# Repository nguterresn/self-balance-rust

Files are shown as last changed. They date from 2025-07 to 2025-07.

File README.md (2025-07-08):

# Self balacing robot in Rust 🦀

Simple to use and quick to print two wheel robot.

IMG_9873 – média

* [Code](https://github.com/nguterresn/self-balance-rust/tree/master/firmware)
* [Enclosure](https://github.com/nguterresn/self-balance-rust/tree/master/cad)

Requires:

* ESP32C3 (or equivalent)
* DRV8833 driver (or equivalent)
* MPU6050
* x2 n20 motor
* A battery (used a 7.4V one)
* x4 M3 screws (bottom)
* x4 M3 screws (lid)
* A small breadboard

The code is written in Rust and runs in a single loop. Due the single loop operation, the timings may not be the best, but the goal was achieved. I tried to wrap all the possible errors that could happen inside the main loop in such a way that it would not cause any strange _panic_ in case of error.

This is essentially an exploration of what can be achieved when Rust and the robotics field is mixed.

I'd like to point out a few things:

* Calibration.
* PID control.
* Slow/Fast Decay.
* PWM frequency.
* Wheels size.
* Gyro and accel direction.
* Filters.
* I2C packet loss/ FIFO packet loss.
* Starting angle.

All the above had some kind of impact in the development of the project. 

Since the motors do not include a encoder, the following project scope is only within the angle error mitigation, the so called "balance". Therefore, it does not garantee any cascade control.

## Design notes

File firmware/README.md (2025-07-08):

To run the PID live visualization:

```bash
python3 sim.py
```

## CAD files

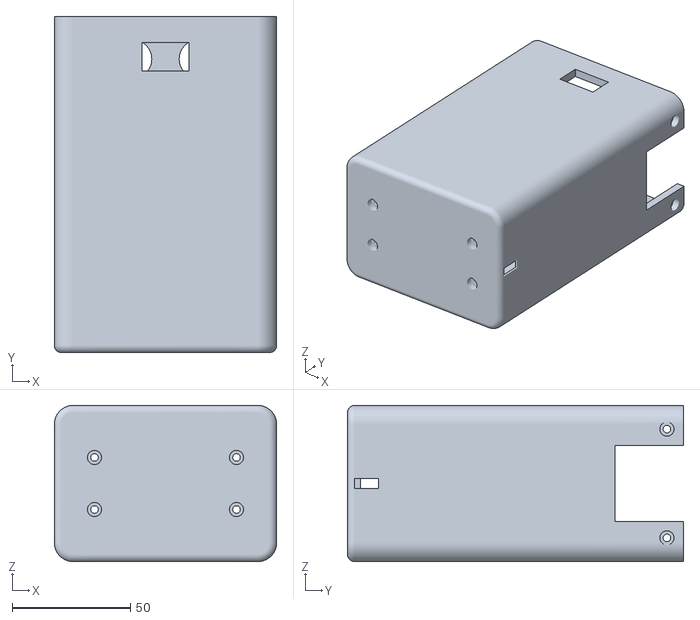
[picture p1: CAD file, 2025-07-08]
cad/Body.stl
94.0 x 142.0 x 66.0

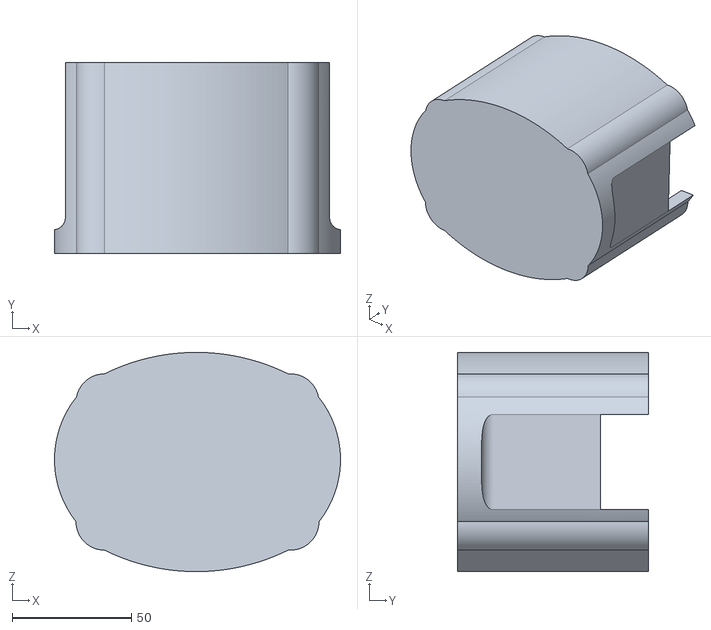
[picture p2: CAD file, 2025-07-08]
cad/Garage.stl
120.0 x 80.0 x 92.0

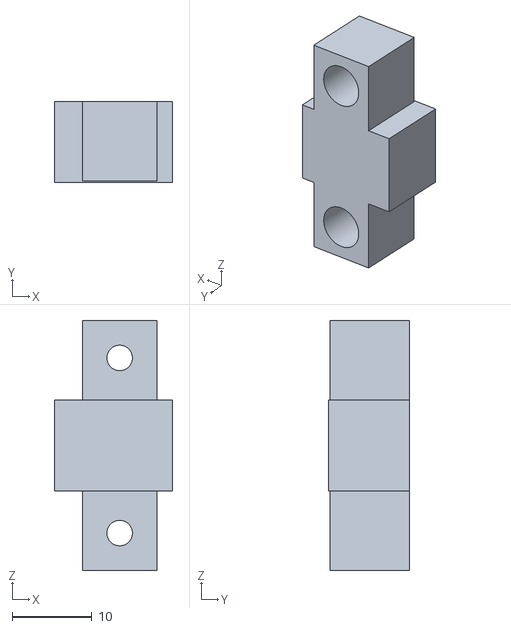
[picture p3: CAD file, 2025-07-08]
cad/Holder.stl
14.8 x 10.2 x 31.4

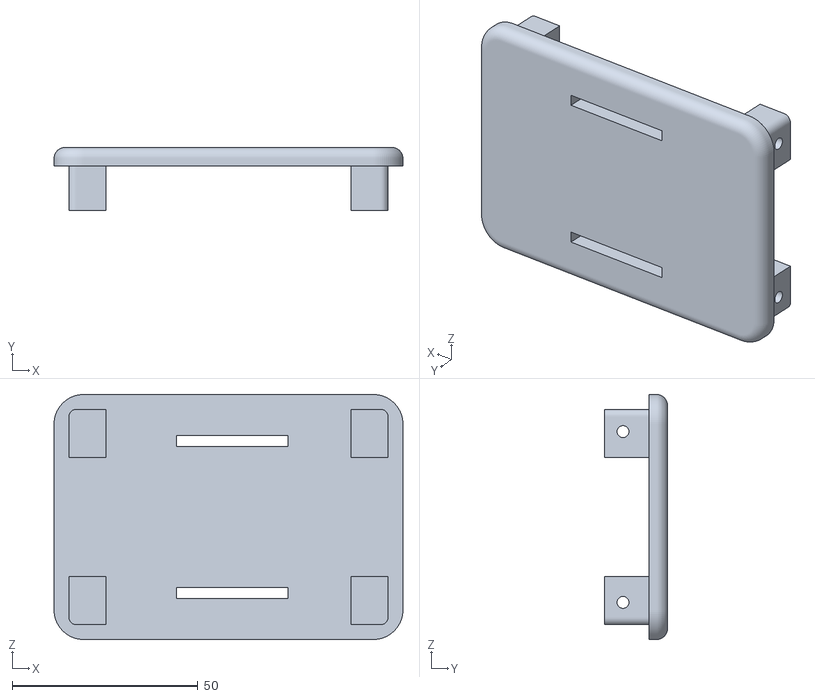
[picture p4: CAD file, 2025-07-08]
cad/Lid.stl
94.0 x 17.0 x 66.0

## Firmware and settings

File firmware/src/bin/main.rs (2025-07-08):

#![no_std]
#![no_main]

use esp_drv8833::drv8833::MotorLink;
use esp_drv8833::MotorTimer;
use esp_hal::clock::CpuClock;
use esp_hal::delay::Delay;
use esp_hal::i2c::master::{Config, I2c};
use esp_hal::ledc::{channel, timer, LSGlobalClkSource, Ledc};
use esp_hal::time::{Instant, Rate};
use esp_hal::{main, Blocking};
use esp_println::println;
use firmware::{BalanceControl, BalanceRobot};
use mpu6050_dmp::accel::{Accel, AccelFullScale};
use mpu6050_dmp::address::Address;
// use mpu6050_dmp::calibration::{CalibrationParameters, ReferenceGravity};
use mpu6050_dmp::error::Error;
use mpu6050_dmp::gyro::{Gyro, GyroFullScale};
use mpu6050_dmp::quaternion::Quaternion;
use mpu6050_dmp::sensor::Mpu6050;
use mpu6050_dmp::yaw_pitch_roll::YawPitchRoll;

#[panic_handler]
fn panic(info: &core::panic::PanicInfo) -> ! {
    println!("Panic! Msg: {}:{:?}", info.message(), info.location());
    loop {}
}

// First pair of values: (Accel { x: -52, y: 36, z: 16384 }, Gyro { x: 7, y: 7, z: 8 })

#[main]
fn main() -> ! {
    // generator version: 0.3.1

    let config = esp_hal::Config::default().with_cpu_clock(CpuClock::max());
    let peripherals = esp_hal::init(config);

    let mut ledc = Ledc::new(peripherals.LEDC);
    ledc.set_global_slow_clock(LSGlobalClkSource::APBClk);

    let motor_config = MotorTimer::new(
        &ledc,
        timer::Number::Timer0,
        timer::config::Duty::Duty7Bit,
        Rate::from_hz(500),
    )
    .unwrap();

    let mut robot = BalanceRobot::new(
        &ledc,
        &motor_config.timer,
        MotorLink::new(channel::Number::Channel1, peripherals.GPIO0),
        MotorLink::new(channel::Number::Channel0, peripherals.GPIO1),
        MotorLink::new(channel::Number::Channel3, peripherals.GPIO10),
        MotorLink::new(channel::Number::Channel2, peripherals.GPIO9),
    )
    .unwrap();
    robot.brake().unwrap();

    let mut delay = Delay::new();
    delay.delay_millis(1000);

    // Setup correctly the accelerometer

    let i2c = I2c::new(peripherals.I2C0, Config::default())
        .unwrap()
        .with_sda(peripherals.GPIO4)
        .with_scl(peripherals.GPIO3);

    let mut sensor: Mpu6050<I2c<'_, esp_hal::Blocking>> =
        Mpu6050::new(i2c, Address::default()).unwrap();

    let offsets = (Accel::new(-2656, -1231, 797), Gyro::new(181, -9, 26));

    sensor.initialize_dmp(&mut delay).unwrap();
    sensor.set_accel_full_scale(AccelFullScale::G2).unwrap();
    sensor.set_gyro_full_scale(GyroFullScale::Deg250).unwrap();
    sensor.set_accel_calibration(&offsets.0).unwrap();
    sensor.set_gyro_calibration(&offsets.1).unwrap();

    // let values = sensor
    //     .calibrate(
    //         &mut delay,
    //         &CalibrationParameters::new(
    //             AccelFullScale::G2,
    //             GyroFullScale::Deg250,
    //             ReferenceGravity::ZP,
    //         ),
    //     )
    //     .unwrap();

    // println!("Calibration: {:?}", values);

    let temp = sensor.temperature().unwrap();
    println!("Temperature: {}°C", temp.celsius());

    sensor.reset_fifo().unwrap();

    const PI: f32 = 3.141592653589793;
    let mut control = BalanceControl::new(0.00, 800.0, 0.0, 3500.0);
    let mut pitch: f32 = 0.0;
    let mut last = 0;

    loop {
        let count = match sensor.get_fifo_count() {
            Ok(count) => count,
            Err(_) => continue,
        };

        if count >= 1024 {
            panic!("FIFO is full!");
        }

        // Sample rate of around ~5ms!
        if count >= 28 {
            pitch = match get_pitch(&mut sensor) {
                Ok(pitch) => pitch,
                Err(_) => continue,
            };
        }

        let dt = Instant::now().duration_since_epoch().as_micros() - last;
        if dt >= 5_000 {
            let (duty, error, p, i, d) = control.calc_duty(pitch);
            last = Instant::now().duration_since_epoch().as_micros();
            let angle = pitch * 180.0 / PI;

            match drive_robot(&mut robot, angle, duty) {
                Ok(_) => println!("{},{},{},{},{},{}", duty, angle, error, p, i, d),
                Err(_) => continue,
            }
        }
    }
}

fn get_pitch<'a>(sensor: &mut Mpu6050<I2c<'a, Blocking>>) -> Result<f32, Error<I2c<'a, Blocking>>> {
    let mut buf: [u8; 28] = [0; 28];
    let fifo = sensor.read_fifo(&mut buf)?;
    sensor.reset_fifo()?;

    let q = Quaternion::from_bytes(&fifo[..16])
        .ok_or(Error::WrongDevice)?
        .normalize();
    Ok(YawPitchRoll::from(q).pitch)
}

fn drive_robot(
    robot: &mut BalanceRobot,
    angle: f32,
    duty: i8,
) -> Result<(), esp_drv8833::drv8833::Error> {
    if angle > 30.0 || angle < -30.0 {
        robot.brake()?;
    } else {
        let value = duty.abs() as u8;
        if duty > 0 {
            robot.backwards(value)?;
        } else {
            robot.forward(value)?;
        }
    }

    Ok(())
}

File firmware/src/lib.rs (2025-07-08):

#![no_std]

use esp_drv8833::{
    drv8833::{Error, MotorLink},
    Motor, MotorInterface, MotorSlowDecay,
};
use esp_hal::{
    gpio::interconnect::PeripheralOutput,
    ledc::{timer::Timer, Ledc, LowSpeed},
};

pub struct BalanceRobot<'a> {
    motor_right: MotorSlowDecay<'a>,
    motor_left: MotorSlowDecay<'a>,
}

impl<'a> BalanceRobot<'a> {
    pub fn new<A, B, C, D>(
        ledc: &'a Ledc<'a>,
        timer: &'a Timer<'a, LowSpeed>,
        m_r_a: MotorLink<A>,
        m_r_b: MotorLink<B>,
        m_l_a: MotorLink<C>,
        m_l_b: MotorLink<D>,
    ) -> Result<Self, Error>
    where
        A: for<'any> PeripheralOutput<'any>,
        B: for<'any> PeripheralOutput<'any>,
        C: for<'any> PeripheralOutput<'any>,
        D: for<'any> PeripheralOutput<'any>,
    {
        // Create the right motor
        let motor_right: MotorSlowDecay = Motor::new(ledc, timer, m_r_a, m_r_b)?;
        // Create the left motor
        let motor_left: MotorSlowDecay = Motor::new(ledc, timer, m_l_a, m_l_b)?;

        Ok(Self {
            motor_right,
            motor_left,
        })
    }

    pub fn brake(&self) -> Result<(), Error> {
        self.motor_left.brake()?;
        self.motor_right.brake()?;

        Ok(())
    }

    pub fn forward(&mut self, duty: u8) -> Result<(), Error> {
        self.motor_left.forward(duty)?;
        self.motor_right.forward(duty)?;

        Ok(())
    }

    pub fn backwards(&mut self, duty: u8) -> Result<(), Error> {
        self.motor_left.backward(duty)?;
        self.motor_right.backward(duty)?;

        Ok(())
    }

    pub fn turn_right(&mut self, duty: u8) -> Result<(), Error> {
        self.motor_left.forward(duty)?;
        self.motor_right.backward(duty)?;

        Ok(())
    }

    pub fn turn_left(&mut self, duty: u8) -> Result<(), Error> {
        self.motor_left.backward(duty)?;
        self.motor_right.forward(duty)?;

        Ok(())
    }
}

#[derive(Default)]
pub struct BalanceControl {
    setpoint: f32, // in degrees
    kp: f32,
    ki: f32,
    kd: f32,
    error_sum: f32,
    previous_input: f32,
}

impl BalanceControl {
    pub fn new(setpoint: f32, kp: f32, ki: f32, kd: f32) -> Self {
        Self {
            setpoint,
            kp,
            ki,
            kd,
            error_sum: f32::default(),
            previous_input: f32::default(),
        }
    }

    pub fn calc_duty(&mut self, input: f32) -> (i8, f32, f32, f32, f32) {
        let error = self.setpoint - input;
        let d_input = input - self.previous_input;

        self.previous_input = input;

        let proportional = self.kp * error;
        self.error_sum = self.error_sum.clamp(-10.0, 10.0) + error;

        let integral = self.ki * self.error_sum;
        let derivative = self.kd * d_input;

        let out = proportional + integral - derivative;

        // Motor deadband.
        // if out > 0.0 {
        //     out += 10.0;
        // }

        // if out < 0.0 {
        //     out -= 10.0;
        // }

        return (
            out.clamp(-100.0, 100.0) as i8,
            error,
            proportional,
            integral,
            derivative,
        );
    }
}
